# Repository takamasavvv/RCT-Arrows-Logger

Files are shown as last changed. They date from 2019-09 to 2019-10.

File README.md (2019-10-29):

# RCT-Arrows-Logger
 Logger module for GS-8  
circuit

Fab  

B_Cu  
F_Cu  
B_SilkS  
F_SilkS  
B_Paste  
F_Paste  
B_Mask  
F_Mask  
Edge_Cuts

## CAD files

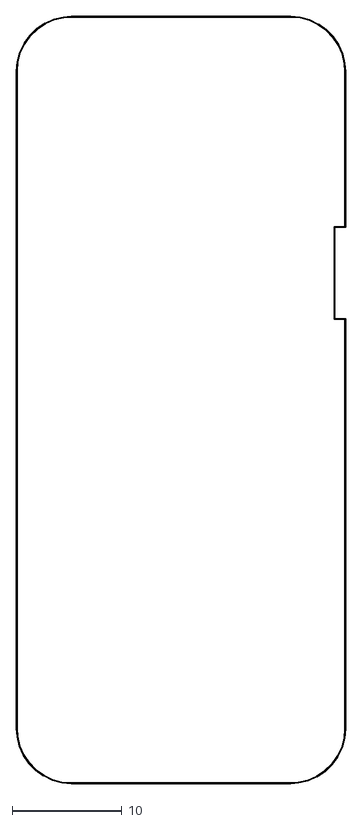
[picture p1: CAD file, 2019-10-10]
dxf/RCT-X-Logger-Edge_Cuts.dxf
30.1 x 70.1

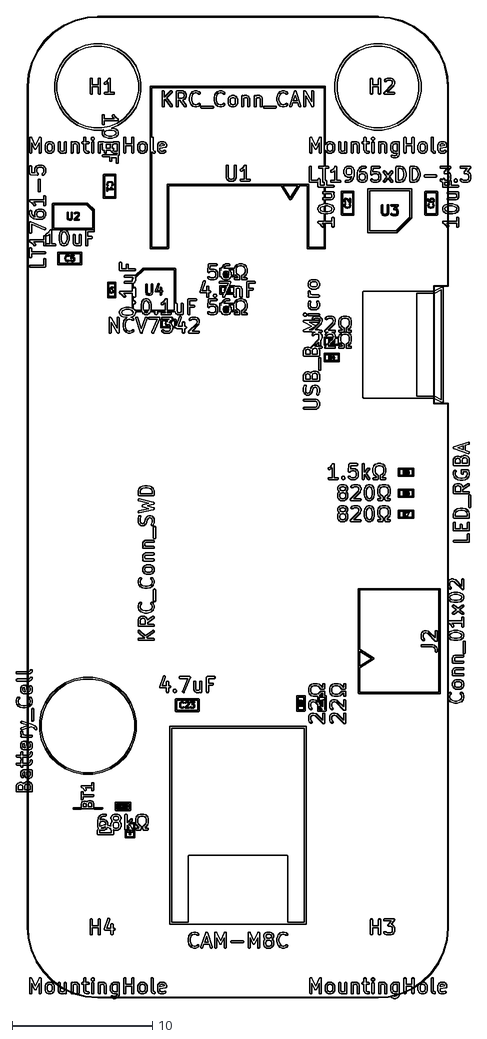
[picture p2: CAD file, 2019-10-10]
dxf/RCT-X-Logger-F_Fab.dxf
32.4 x 70.1

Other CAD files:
dxf/RCT-X-Logger-B_SilkS.dxf
dxf/RCT-X-Logger-F_SilkS.dxf

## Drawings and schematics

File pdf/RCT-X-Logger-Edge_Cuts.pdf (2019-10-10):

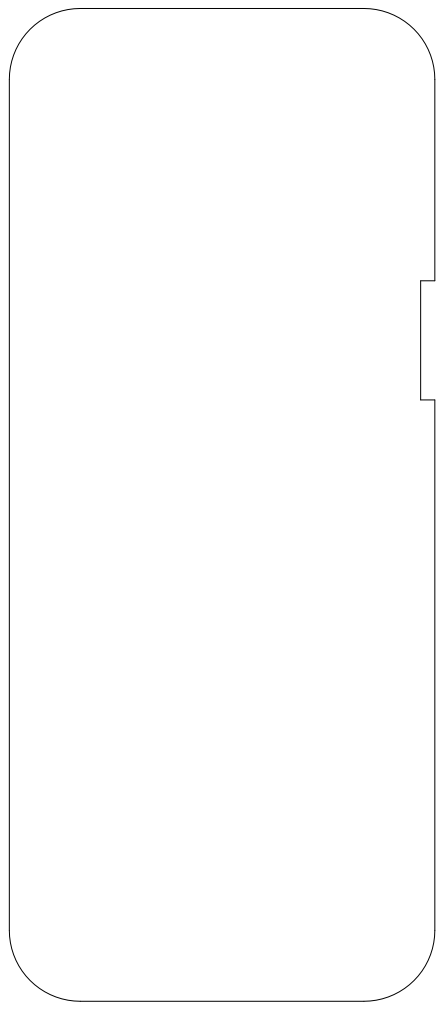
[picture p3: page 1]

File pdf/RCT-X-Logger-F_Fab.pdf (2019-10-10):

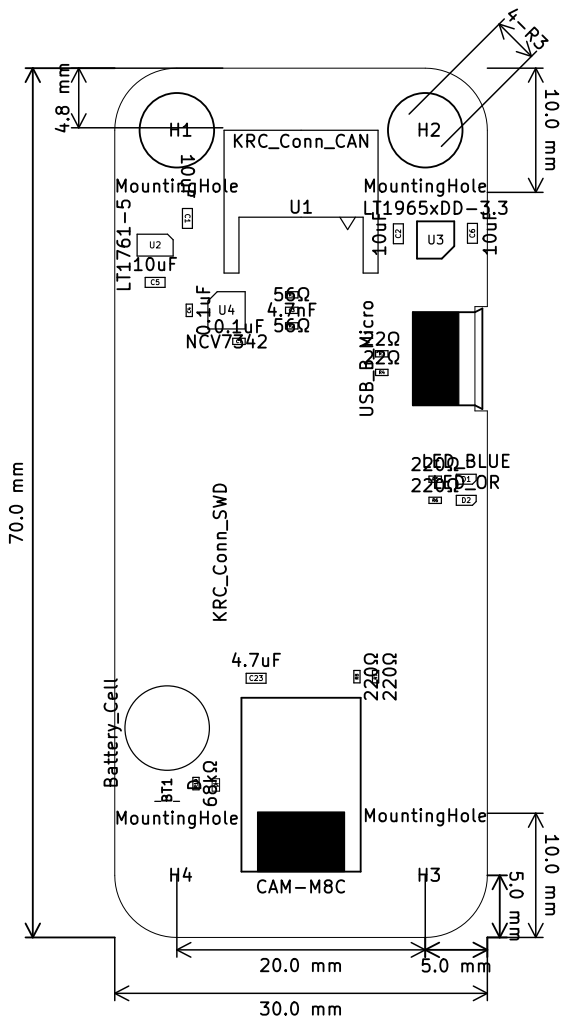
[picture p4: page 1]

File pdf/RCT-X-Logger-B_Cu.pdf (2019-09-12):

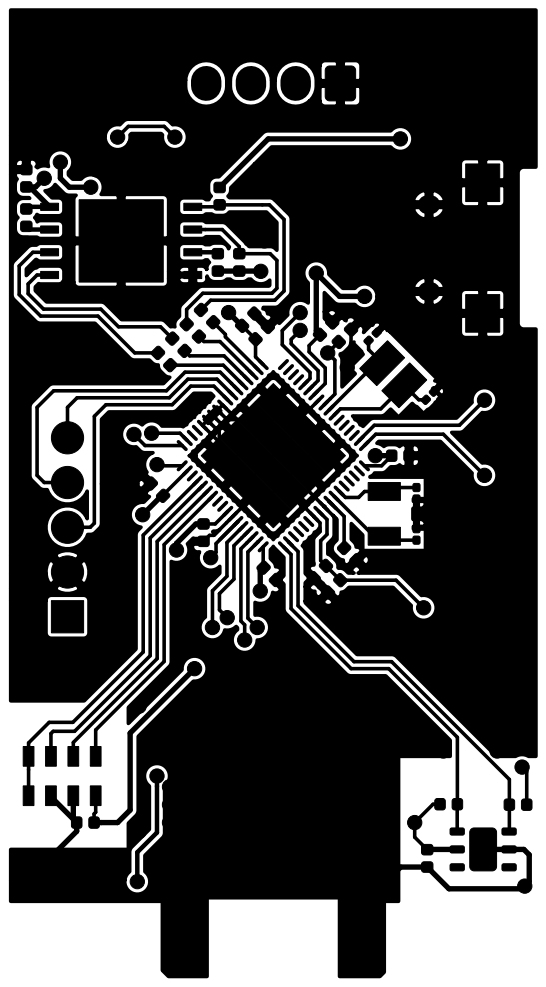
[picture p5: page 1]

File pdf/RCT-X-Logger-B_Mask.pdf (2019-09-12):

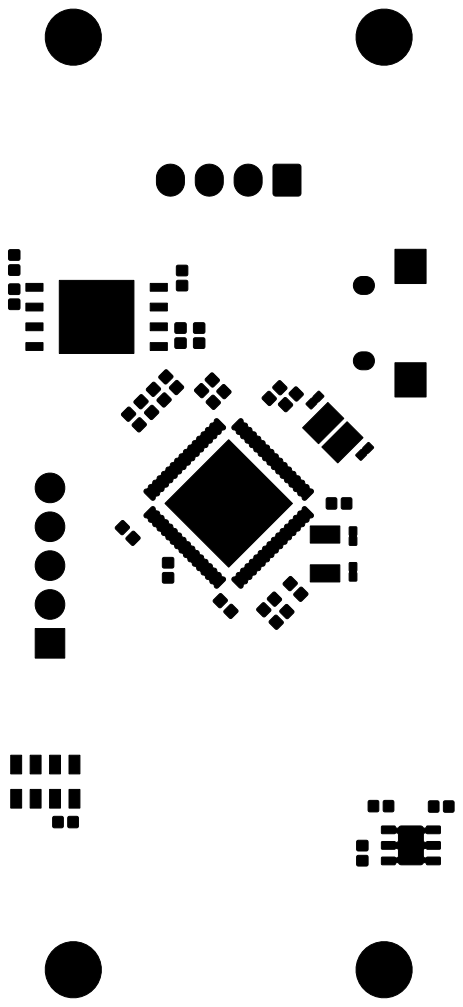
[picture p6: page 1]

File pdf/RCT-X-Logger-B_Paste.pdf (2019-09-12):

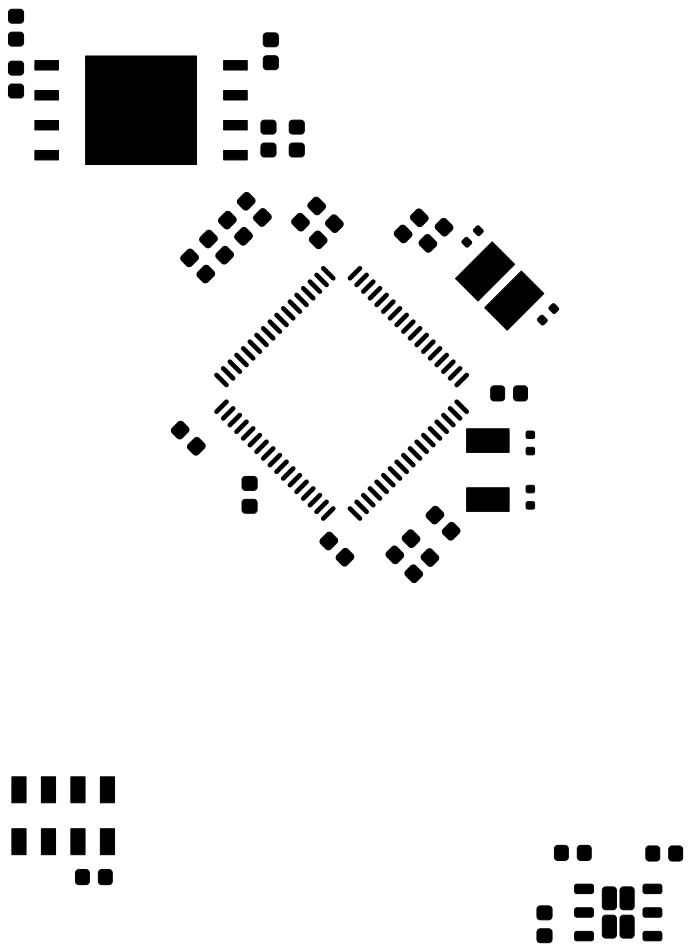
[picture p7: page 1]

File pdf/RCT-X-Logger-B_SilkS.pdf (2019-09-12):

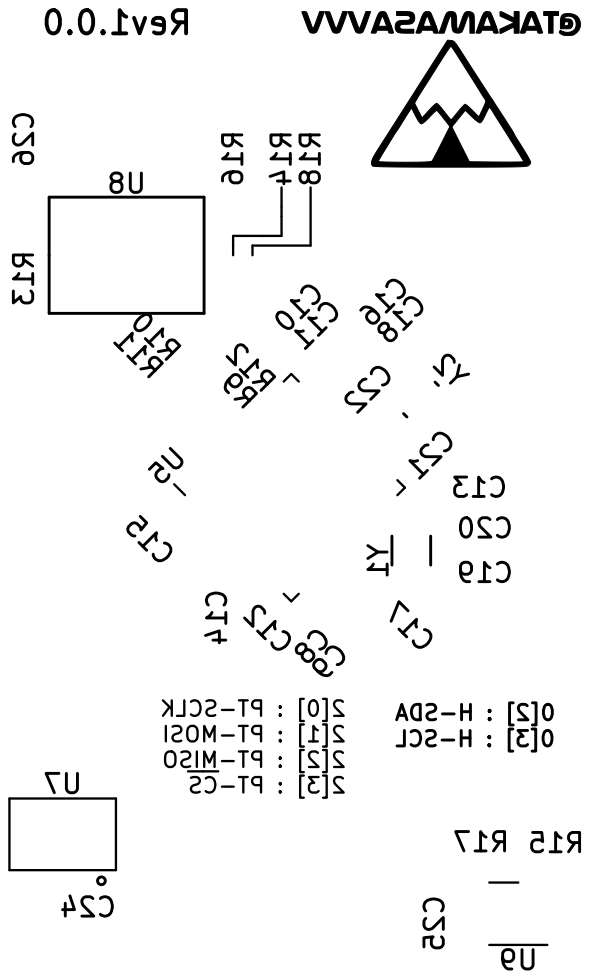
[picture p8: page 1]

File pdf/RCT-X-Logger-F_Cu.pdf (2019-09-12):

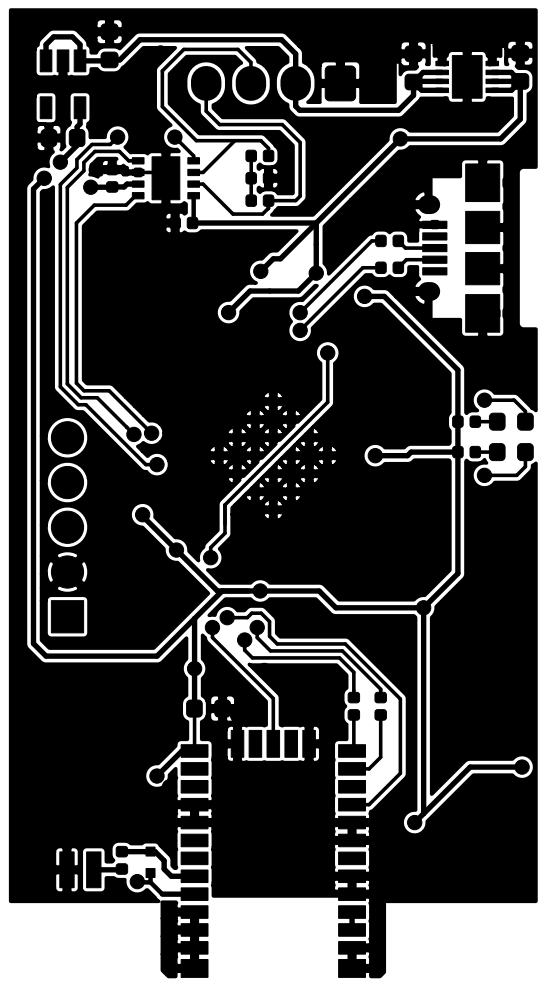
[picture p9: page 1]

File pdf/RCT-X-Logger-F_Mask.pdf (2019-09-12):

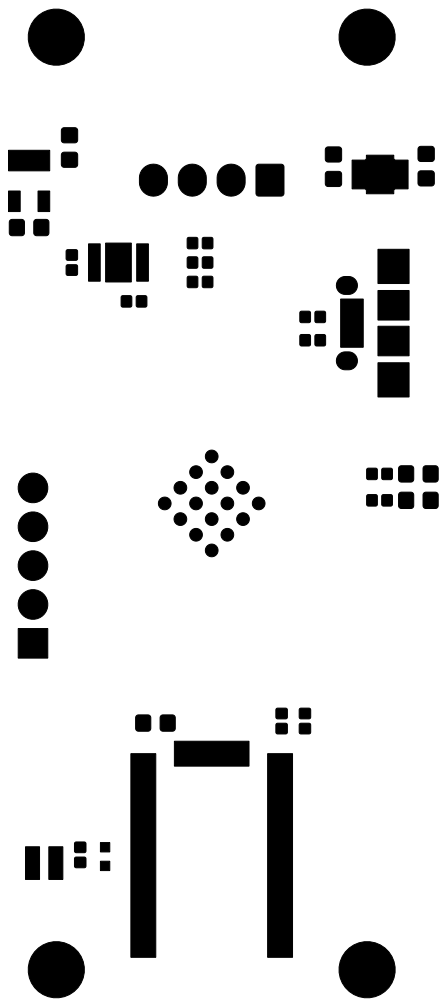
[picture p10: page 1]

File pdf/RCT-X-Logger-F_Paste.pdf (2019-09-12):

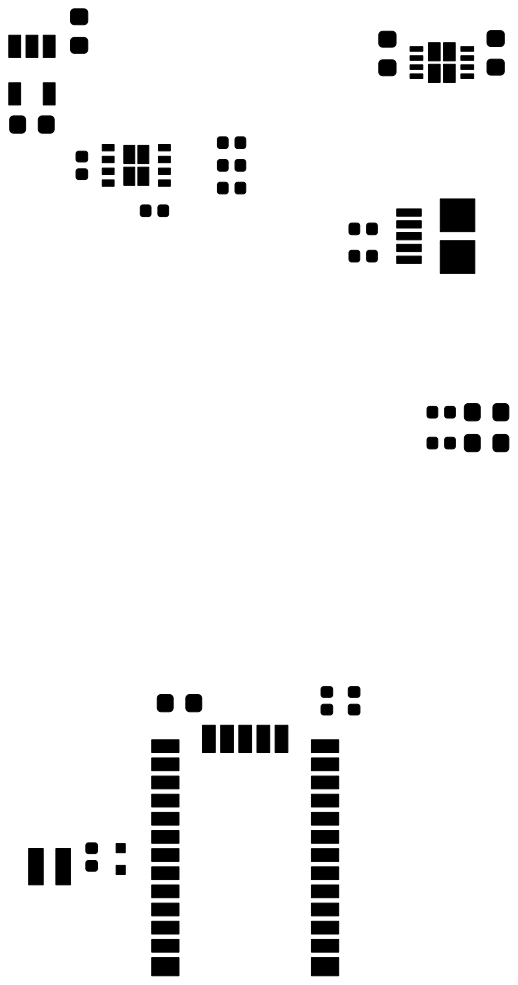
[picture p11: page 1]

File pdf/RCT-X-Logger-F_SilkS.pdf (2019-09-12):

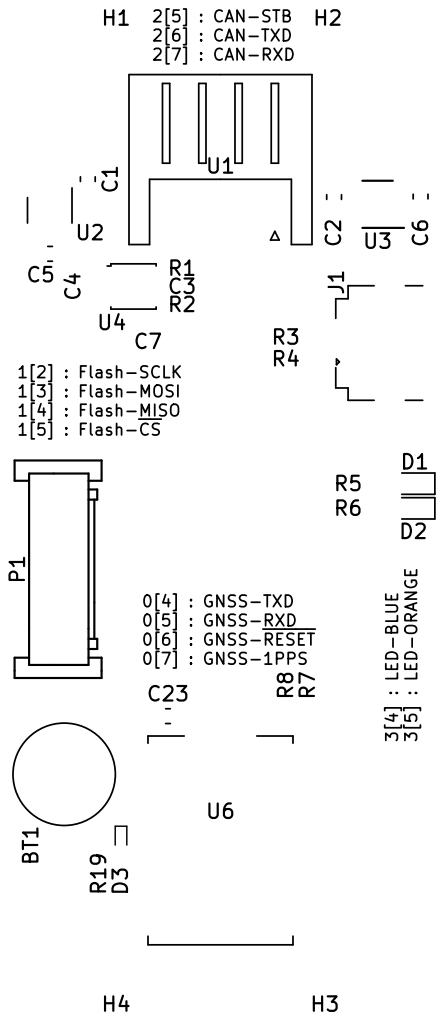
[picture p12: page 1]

1[2] : Flash-SCLK
1[3] : Flash-MOSI 1[4] : Flash-MISO
1[5] : Flash-CS

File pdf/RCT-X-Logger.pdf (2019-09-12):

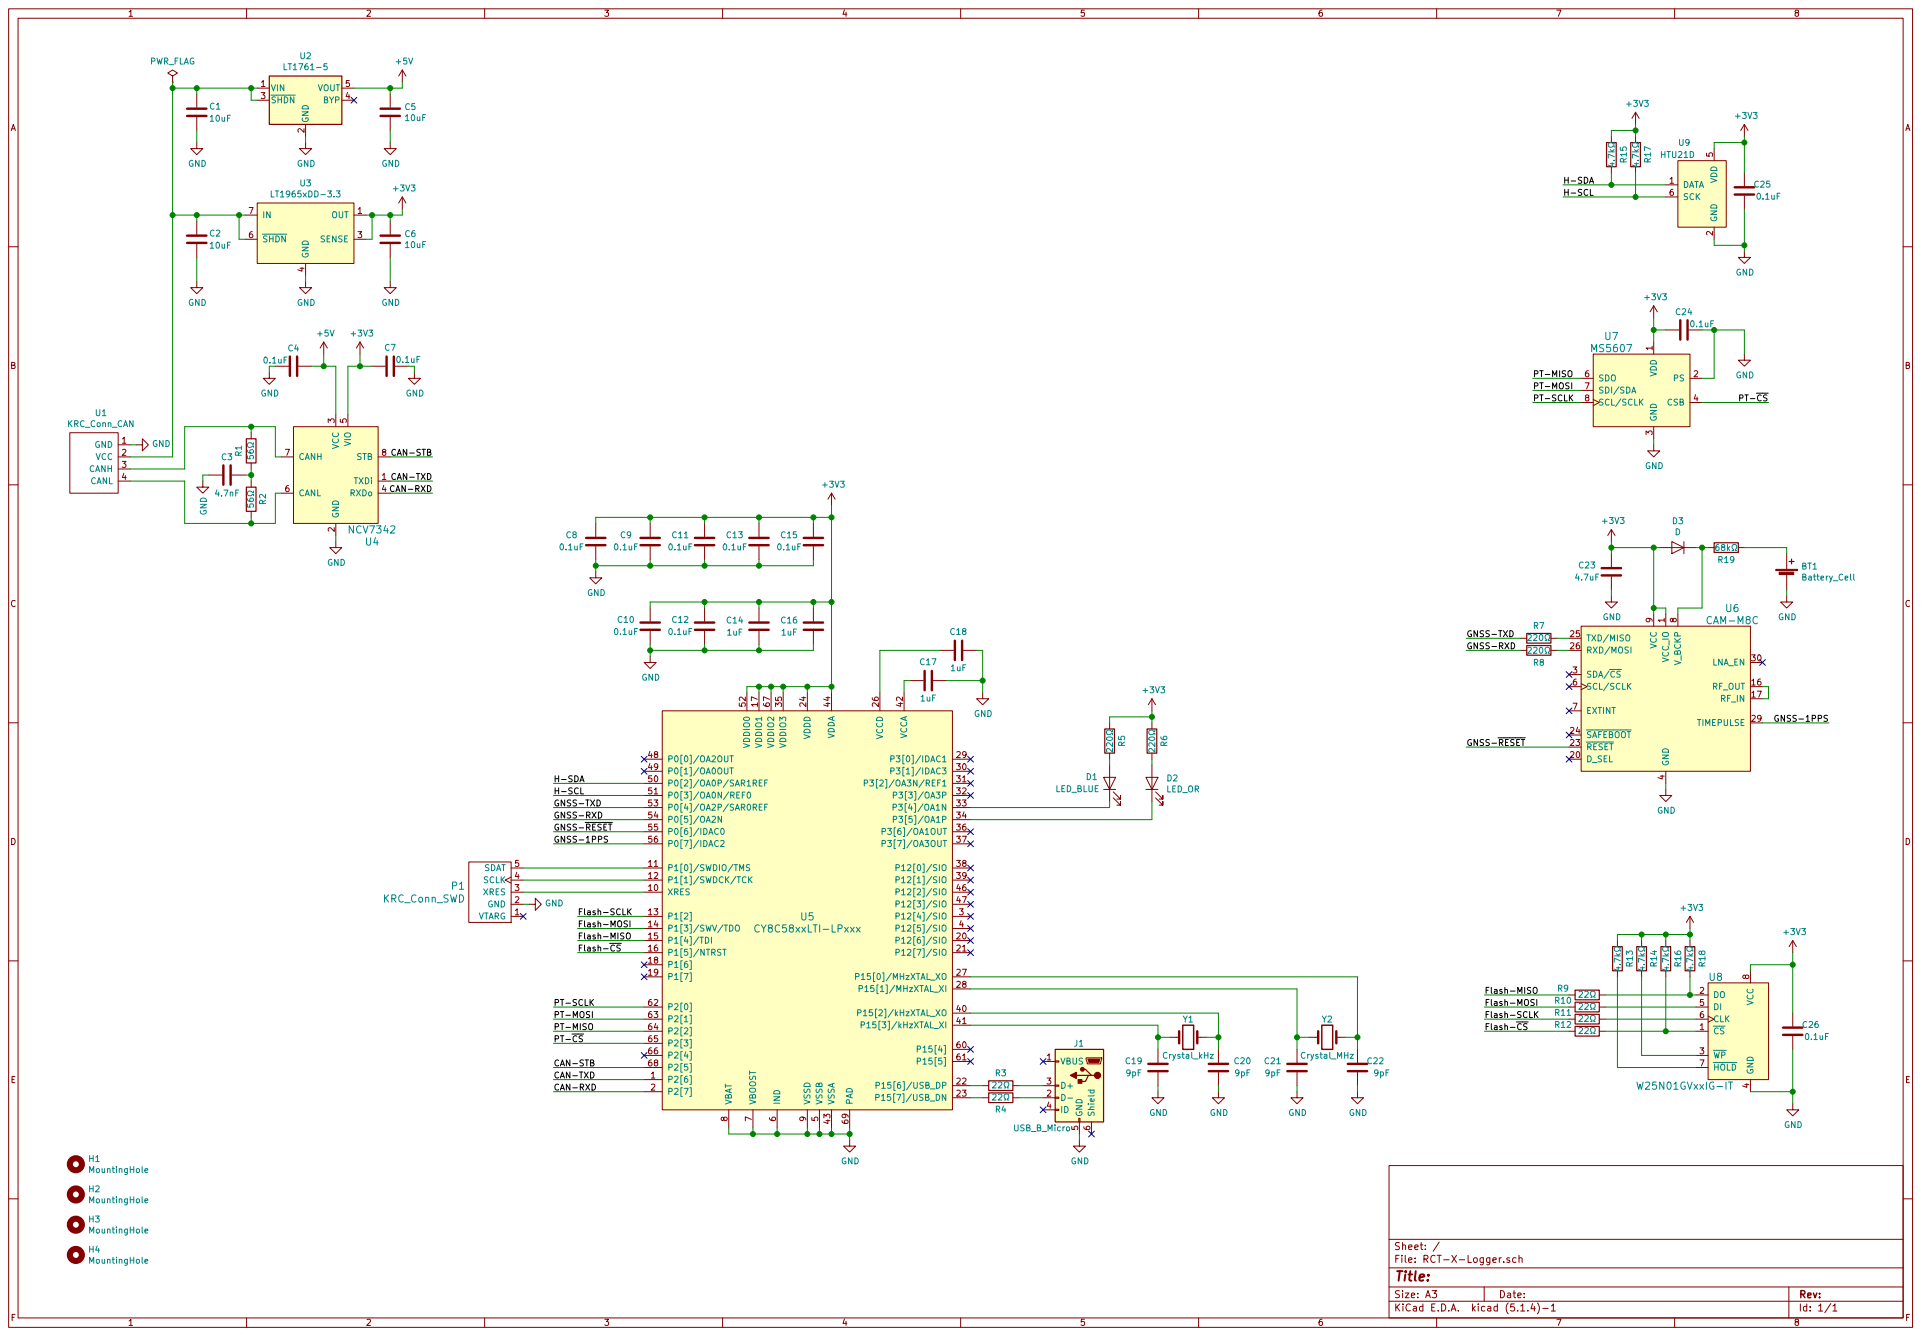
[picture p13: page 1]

220 GNSS-TXD
Flash-SCLK GNSS-RXD GNSS-RESET GNSS-1PPS H-SDA H-SCLFlash-MISO

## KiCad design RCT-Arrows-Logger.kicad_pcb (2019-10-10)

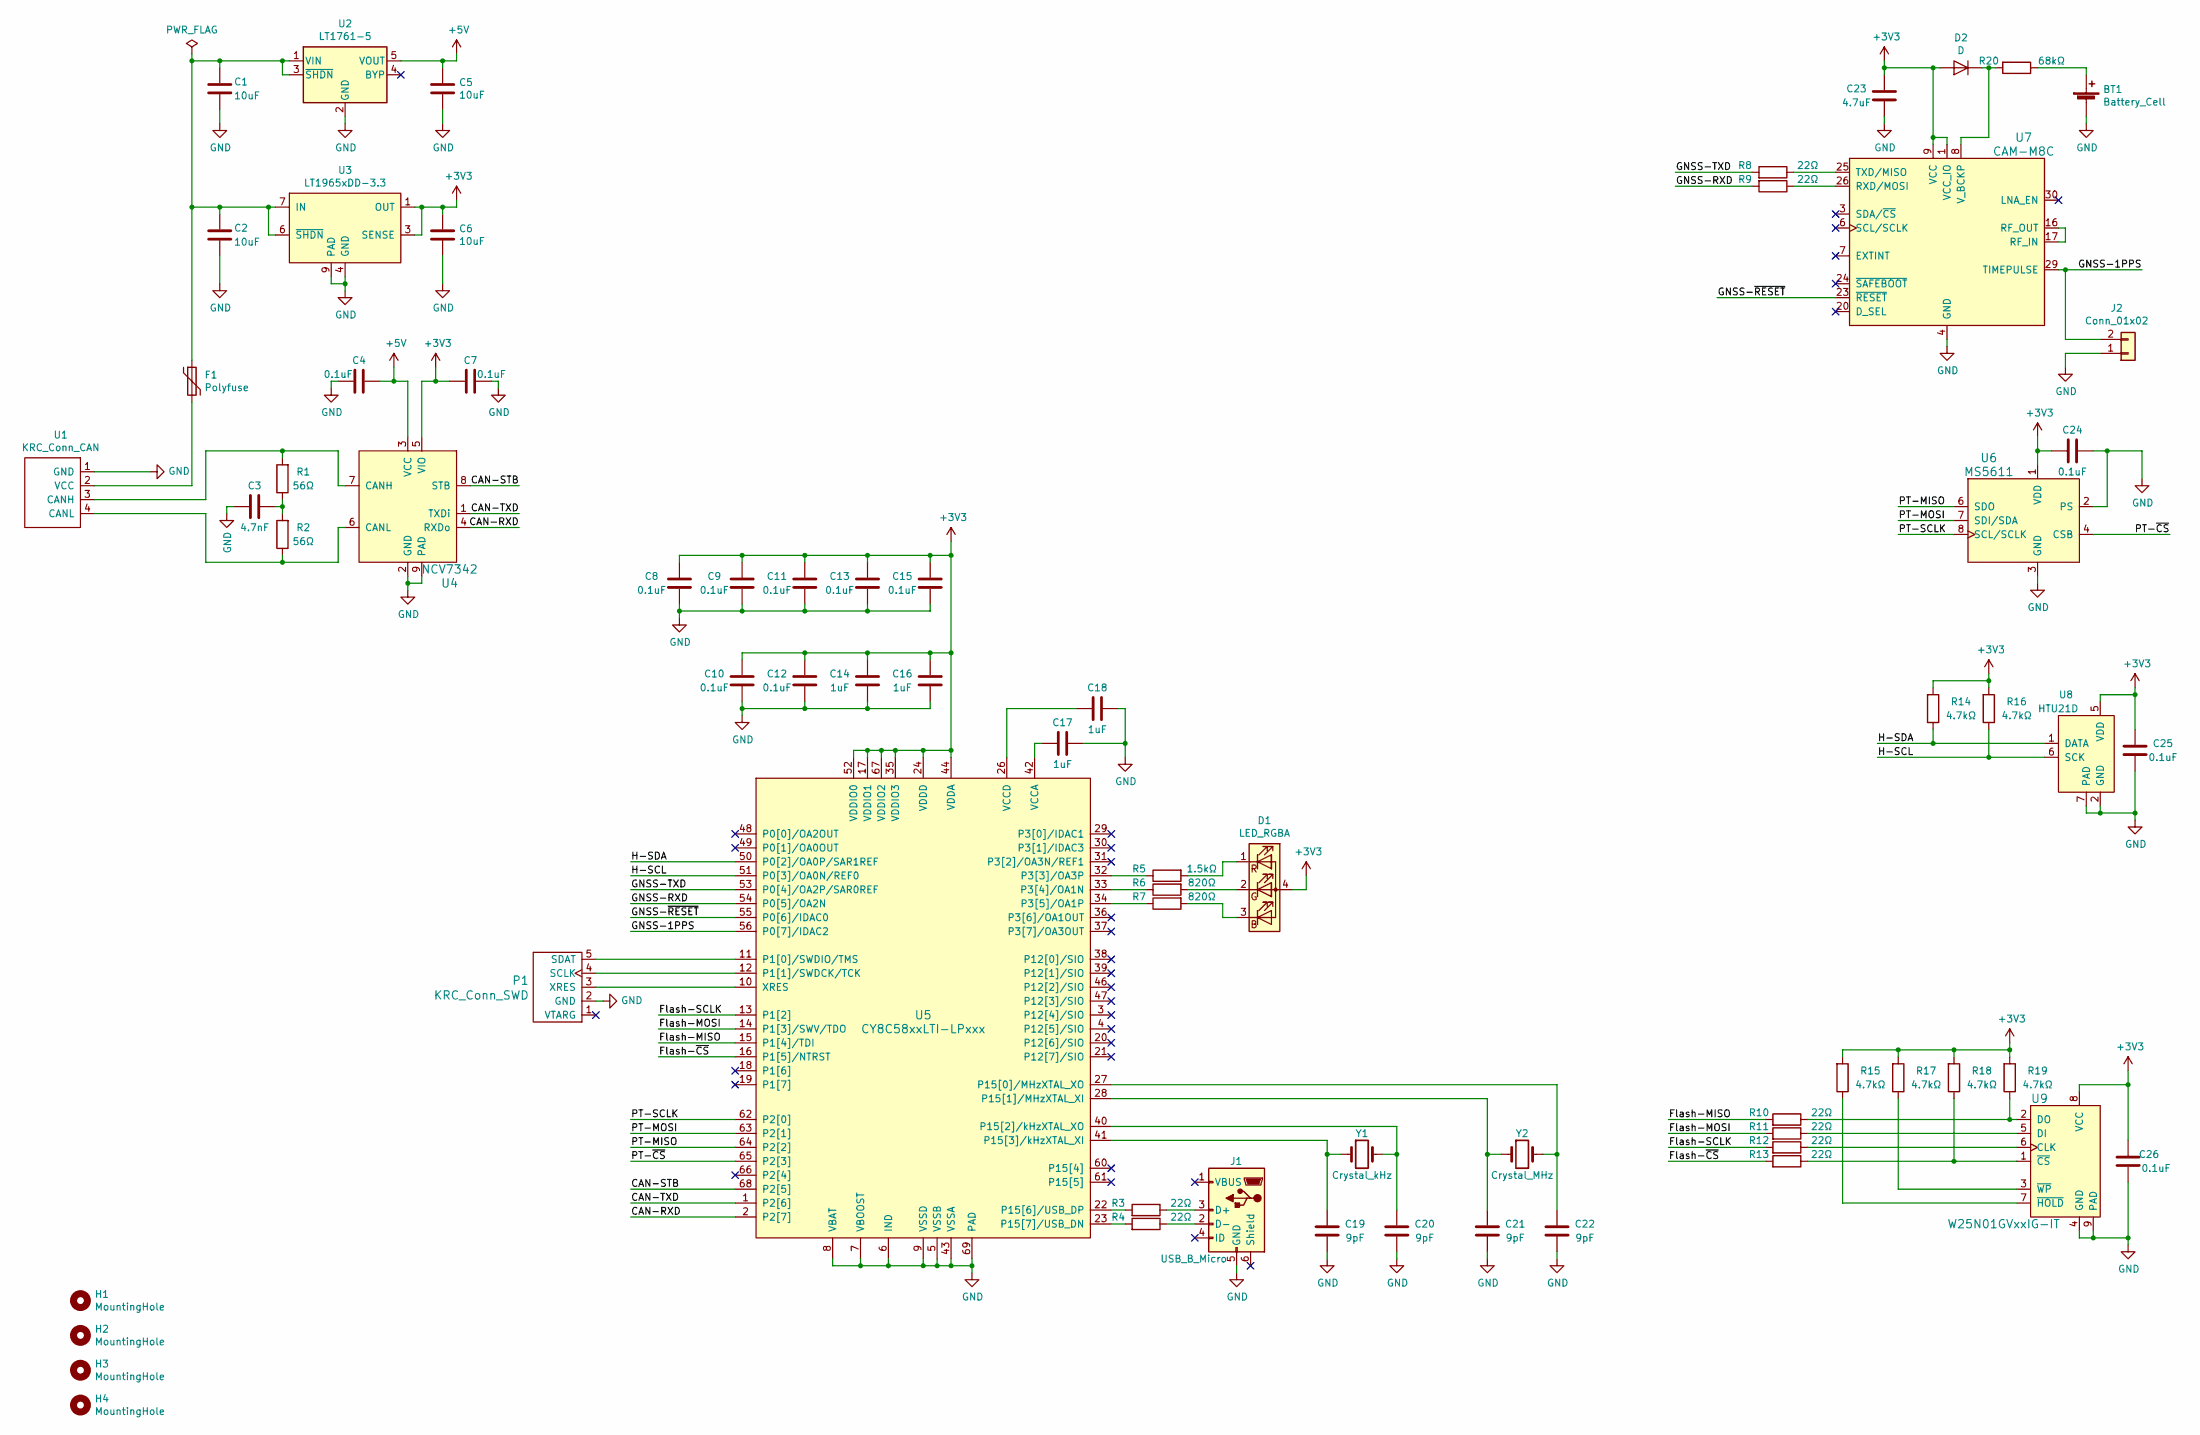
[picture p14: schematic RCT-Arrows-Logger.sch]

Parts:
BT1: Battery_Cell; BatteryHolder_Seiko_MS621F; MPN MS621FE
C1, C2, C5, C6: 10uF; C_0603_1608Metric; MPN GRM188R61E106MA73D
C3: 4.7nF; C_0402_1005Metric; MPN GRM155R71H472KA01D
C4, C7, C8, C9, C10, C11, C12, C13, C15, C24, C25, C26: 0.1uF; C_0402_1005Metric; MPN GRM155R62A104KE14D
C14, C16, C17, C18: 1uF; C_0402_1005Metric; MPN GRM155R61E105KA12D
C19, C20, C21, C22: 9pF; C_0201_0603Metric; MPN GRM0335C1E9R0CA01D
C23: 4.7uF; C_0603_1608Metric; MPN GRM185R61C475ME11D
D1: LED_RGBA; LED_LiteOn_LTST-C19HE1WT; MPN LTST-C19HE1WT
D2: D; D_SOD-723; MPN 1SS400GT2R
F1: Polyfuse; Fuse_0805_2012Metric; MPN MF-FSMF035X-2
H1, H2, H3, H4: MountingHole; MountingHole_3.2mm_M3
J1: USB_B_Micro; Hirose_ZX_ZX62D-B-5P8; MPN ZX62D-B-5P8(30)
J2: Conn_01x02; JST_XH_B2B-XH-A_1x02_P2.50mm_Vertical; MPN B2B-XH-A
P1: KRC_Conn_SWD; JST_JQ_05JQ-BT_1x05_P2.5mm_Vertical; MPN 05JQ-BT
R1, R2: 56Ω; R_0402_1005Metric; MPN ERJ-2GEJ560X
R3, R4, R8, R9, R10, R11, R12, R13: 22Ω; R_0402_1005Metric; MPN ERJ-2GEJ220X
R5: 1.5kΩ; R_0402_1005Metric; MPN ERJ-2GEJ152X
R6, R7: 820Ω; R_0402_1005Metric; MPN ERJ-2GEJ821X
R14, R15, R16, R17, R18, R19: 4.7kΩ; R_0402_1005Metric; MPN ERJ-2GEJ472X
R20: 68kΩ; R_0402_1005Metric; MPN ERJ-2GEJ683X
U1: KRC_Conn_CAN; JST_XH_S4B-XH-A_1x04_P2.50mm_Horizontal; MPN S4B-XH-A
U2: LT1761-5; TSOT-23-5; MPN LT1761MPS5-5#TRMPBF
U3: LT1965xDD-3.3; DFN-8-1EP_3x3mm_P0.5mm_EP1.66x2.38mm; MPN LT1965EDD-3.3#PBF
U4: NCV7342; DFN-8-1EP_3x3mm_P0.65mm_EP1.55x2.4mm; MPN NCV7342MW3R2G
U5: CY8C58xxLTI-LPxxx; Cypress_QFN-68_EP_8x8_Pitch0.4mm; MPN CY8C5868LTI-LP039
U6: MS5611; TE_Sensor_MS8607; MPN MS561101BA03-50
U7: CAM-M8C; ublox-CAM; MPN CAM-M8C-0-10
U8: HTU21D; DFN-6-1EP_3x3mm_P1mm_EP1.5x2.4mm; MPN HPP845E131R4
U9: W25N01GVxxIG-IT; WSON-8_8x6mm_P1.27mm; MPN W25N01GVZEIG TR
Y1: Crystal_kHz; Crystal_SeikoEpson_FC-135; MPN FC-135R 32.7680KF-AC3
Y2: Crystal_MHz; Crystal_Murata_XRCHA; MPN XRCHA24M000F0A01R0

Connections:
+3V3: C6.1, C7.1, C8.2, C9.2, C10.2, C11.2, C12.2, C13.2, C14.1, C15.2, C16.1, C23.2, C24.2, C25.2, C26.2, D1.4 (A), D2.2 (A), R14.2, R15.2, R16.2, R17.2, R18.2, R19.2, U3.1 (OUT), U3.2 (OUT), U3.3 (SENSE), U4.5 (VIO), U5.17 (VDDIO1), U5.24 (VDDD), U5.35 (VDDIO3), U5.44 (VDDA), U5.52 (VDDIO0), U5.59 (VDDD), U5.67 (VDDIO2), U6.1 (VDD), U7.1 (VCC_IO), U7.9 (VCC), U8.5 (VDD), U9.8 (VCC)
+5V: C4.1, C5.1, U2.5 (VOUT), U4.3 (VCC)
/CAN-RXD: U4.4 (RXDo), U5.2 (P2[7])
/CAN-STB: U4.8 (STB), U5.68 (P2[5])
/CAN-TXD: U4.1 (TXDi), U5.1 (P2[6])
/Flash-MISO: R10.2, U5.15 (P1[4]/TDI)
/Flash-MOSI: R11.2, U5.14 (P1[3]/SWV/TDO)
/Flash-SCLK: R12.2, U5.13 (P1[2])
/Flash-~CS: R13.2, U5.16 (P1[5]/NTRST)
/GNSS-1PPS: J2.2, U5.56 (P0[7]/IDAC2), U7.29 (TIMEPULSE)
/GNSS-RXD: R9.2, U5.54 (P0[5]/OA2N)
/GNSS-TXD: R8.2, U5.53 (P0[4]/OA2P/SAR0REF)
/GNSS-~RESET: U5.55 (P0[6]/IDAC0), U7.23 (~RESET)
/H-SCL: R16.1, U5.51 (P0[3]/OA0N/REF0), U8.6 (SCK)
/H-SDA: R14.1, U5.50 (P0[2]/OA0P/SAR1REF), U8.1 (DATA)
/PT-MISO: U5.64 (P2[2]), U6.6 (SDO)
/PT-MOSI: U5.63 (P2[1]), U6.7 (SDI/SDA)
/PT-SCLK: U5.62 (P2[0]), U6.8 (SCL/SCLK)
/PT-~CS: U5.65 (P2[3]), U6.4 (CSB), U6.5 (CSB)
GND: BT1.2 (-), C1.2, C2.2, C3.2, C4.2, C5.2, C6.2, C7.2, C8.1, C9.1, C10.1, C11.1, C12.1, C13.1, C14.2, C15.1, C16.2, C17.2, C18.2, C19.1, C20.1, C21.1, C22.1, C23.1, C24.1, C25.1, C26.1, J1.5 (GND), J2.1, P1.2 (GND), U1.1 (GND), U2.2 (GND), U3.4 (GND), U3.5 (GND), U3.9 (PAD), U4.2 (GND), U4.9 (PAD), U5.5 (VSSB), U5.6 (IND), U5.7 (VBOOST), U5.8 (VBAT), U5.9 (VSSD), U5.25 (VSSD), U5.43 (VSSA), U5.45 (VSSD), U5.58 (VSSD), U5.69 (PAD), U6.2 (PS), U6.3 (GND), U7.4 (GND), U7.5 (GND), U7.10 (GND), U7.11 (GND), U7.12 (GND), U7.13 (GND), U7.14 (GND), U7.15 (GND), U7.18 (GND), U7.19 (GND), U7.21 (GND), U7.22 (GND), U7.27 (GND), U7.31 (GND), U8.2 (GND), U8.7 (PAD), U9.4 (GND), U9.9 (PAD)
unnamed: BT1.1 (+), R20.1
unnamed: C1.1, C2.1, F1.1, U2.1 (VIN), U2.3 (~SHDN), U3.6 (~SHDN), U3.7 (IN), U3.8 (IN)
unnamed: C3.1, R1.1, R2.2
unnamed: C17.1, U5.42 (VCCA)
unnamed: C18.1, U5.26 (VCCD), U5.57 (VCCD)
unnamed: C19.2, U5.41 (P15[3]/kHzXTAL_XI), Y1.1
unnamed: C20.2, U5.40 (P15[2]/kHzXTAL_XO), Y1.2
unnamed: C21.2, U5.28 (P15[1]/MHzXTAL_XI), Y2.1
unnamed: C22.2, U5.27 (P15[0]/MHzXTAL_XO), Y2.2
unnamed: D1.1 (RK), R5.2
unnamed: D1.2 (GK), R6.2
unnamed: D1.3 (BK), R7.2
unnamed: D2.1 (K), R20.2, U7.8 (V_BCKP)
unnamed: F1.2, U1.2 (VCC)
unnamed: J1.2 (D-), R4.1
unnamed: J1.3 (D+), R3.1
unnamed: P1.3 (XRES), U5.10 (XRES)
unnamed: P1.4 (SCLK), U5.12 (P1[1]/SWDCK/TCK)
unnamed: P1.5 (SDAT), U5.11 (P1[0]/SWDIO/TMS)
unnamed: R1.2, U1.3 (CANH), U4.7 (CANH)
unnamed: R2.1, U1.4 (CANL), U4.6 (CANL)
unnamed: R3.2, U5.22 (P15[6]/USB_DP)
unnamed: R4.2, U5.23 (P15[7]/USB_DN)
unnamed: R5.1, U5.32 (P3[3]/OA3P)
unnamed: R6.1, U5.33 (P3[4]/OA1N)
unnamed: R7.1, U5.34 (P3[5]/OA1P)
unnamed: R8.1, U7.25 (TXD/MISO)
unnamed: R9.1, U7.26 (RXD/MOSI)
unnamed: R10.1, R19.1, U9.2 (DO)
unnamed: R11.1, U9.5 (DI)
unnamed: R12.1, U9.6 (CLK)
unnamed: R13.1, R18.1, U9.1 (~CS)
unnamed: R15.1, U9.7 (~HOLD)
unnamed: R17.1, U9.3 (~WP)
unnamed: U7.16 (RF_OUT), U7.17 (RF_IN)

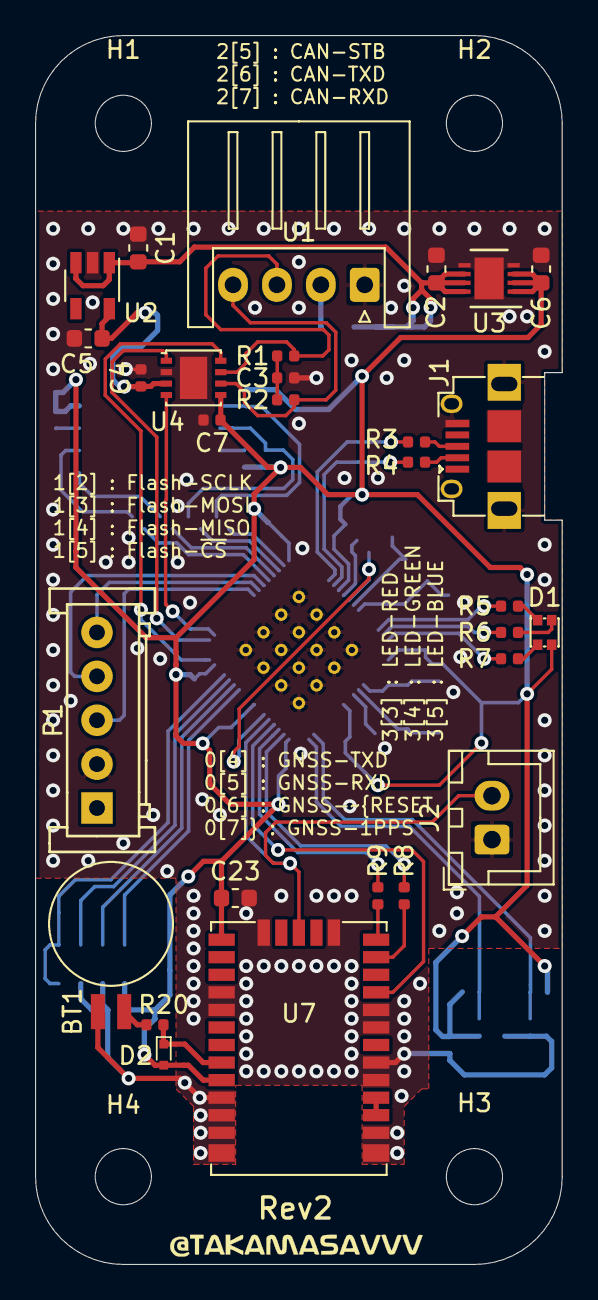
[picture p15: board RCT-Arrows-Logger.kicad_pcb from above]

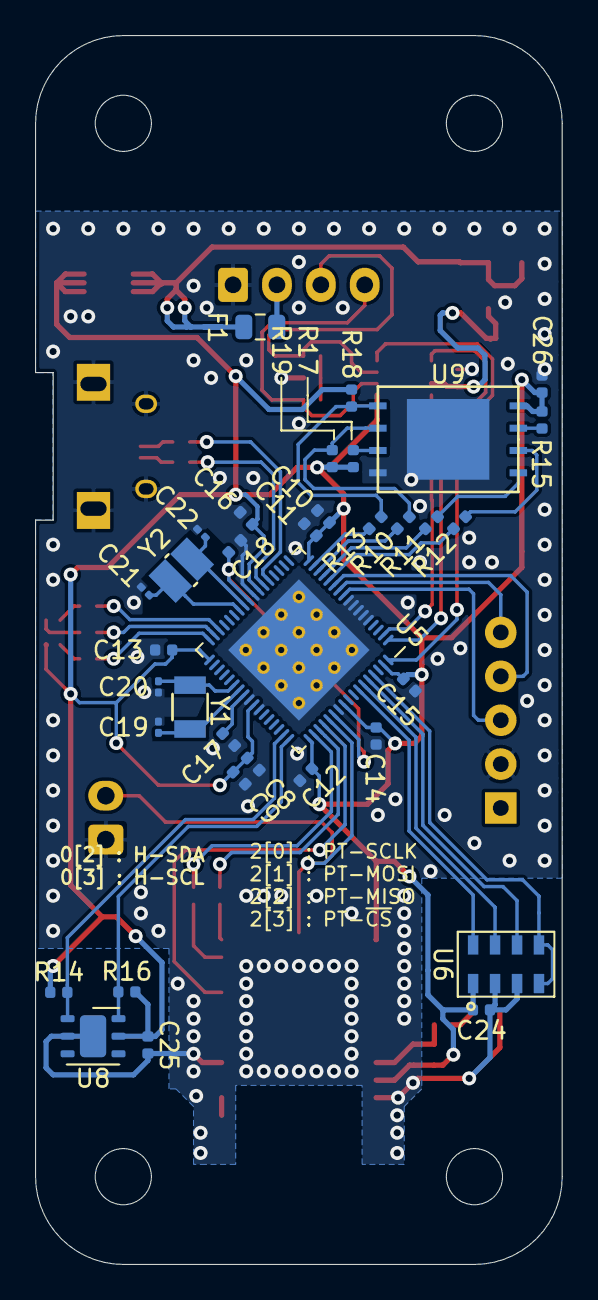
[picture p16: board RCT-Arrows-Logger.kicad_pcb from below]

Board: 2 copper layers, 30.0 x 70.0 mm, 68 parts (35 on the bottom side), 55 nets.

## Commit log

2019-09-06 MountingHole追加
    [RCT-X-Logger.sch]
2019-09-09 [update] 回路初版完成, 部品決定
    [RCT-X-Logger.sch]
2019-09-09 [update] 部品追記
    [RCT-X-Logger.sch]
2019-09-12 アートワークに合わせて配線変更
    [RCT-X-Logger.sch]
2019-09-12 アートワーク完成
    [RCT-X-Logger.kicad_pcb]
2019-09-12 [add]wrote pin asign and logo
    [RCT-X-Logger.kicad_pcb]
2019-09-12 [update]moved ref name (PSoC 5)
    [RCT-X-Logger.sch]
2019-09-12 [update]add size
    [RCT-X-Logger.kicad_pcb]
2019-09-17 [update]moved capacitor placement
    [RCT-X-Logger.kicad_pcb]
2019-10-10 Completed Rev2
    [RCT-X-Logger-B_SilkS.dxf, RCT-X-Logger-Edge_Cuts.dxf, RCT-X-Logger-F_Fab.dxf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]
2019-10-29 rename project
    [RCT-Arrows-Logger.kicad_pcb, RCT-Arrows-Logger.sch]
